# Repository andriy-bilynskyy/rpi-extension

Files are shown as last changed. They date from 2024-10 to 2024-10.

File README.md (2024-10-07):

# Raspberry Pi - Radioberry interconnection board

This project is a PCB design to create SDR transceiver using
Raspberry Pi and Radioberry boards. Simple connection of boards
seems incomplete:

- usually LCD Touch screen is used which creates EMI
- touch screen usually requires I2C bus but it's already used on a Raspberry header
- switching on/off requires USB connection - strange for complete inbox design
- no RTC
- complete design requires BMS monitoring but again I2C is already occupied

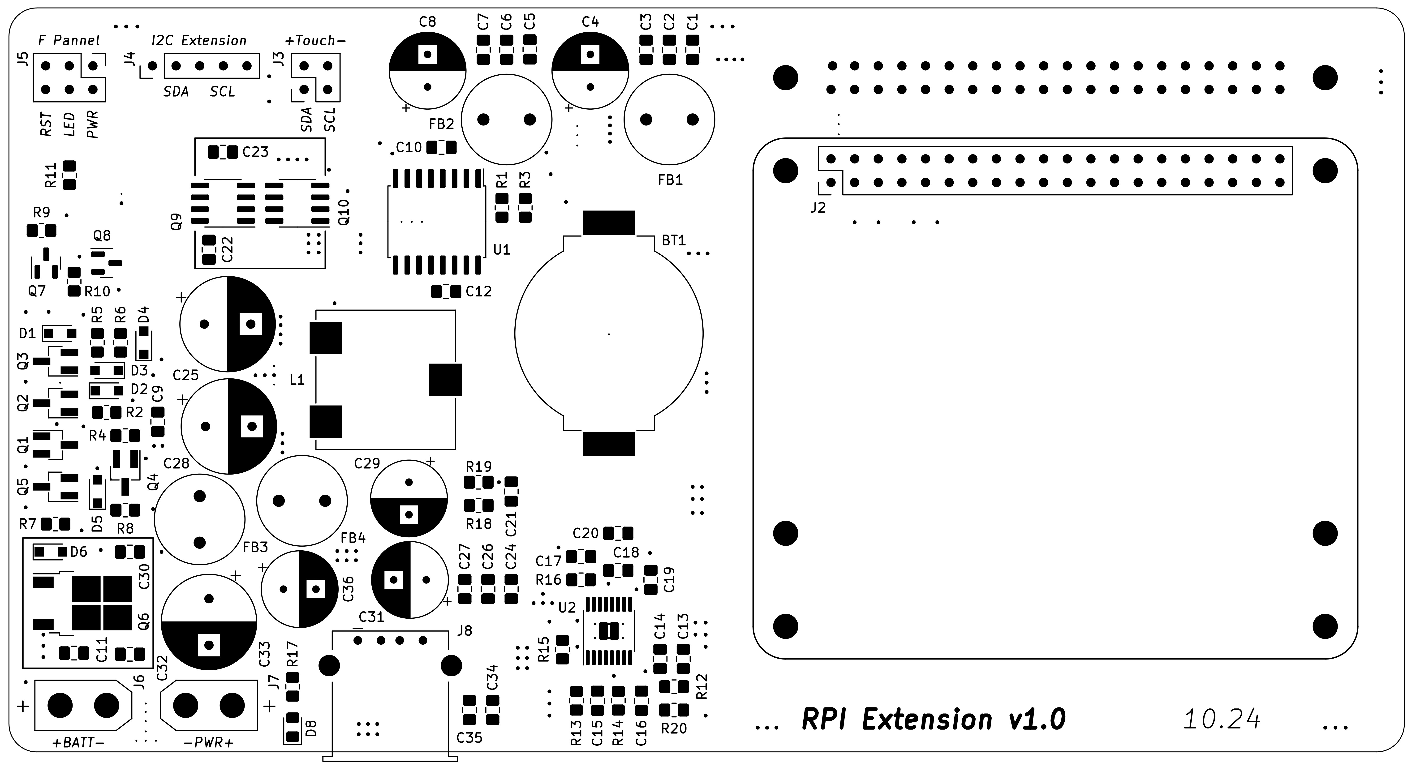
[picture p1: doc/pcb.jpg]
[](doc/pcb.jpg)

## Main Features

- Radioberry shield (mainly EMI caused by LCD touchscreen)
- 12V battery power supply (switching converter to 5V USB)
- ON/OFF circuits with indication
- RTC

For design is used KiCad Version 6.0.11

Documentation is available under **doc** folder

Prepared fabrication files under **gerber** folder

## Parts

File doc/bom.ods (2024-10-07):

Component | Footprint | Count | Designator
ICs
DS3231SN | SO-16 | 1 | U1
TPS40057PWP | HTSSOP-16 | 1 | U2
Transistors
MMBF170LT1G | SOT-23 | 4 | Q1, Q2, Q3, Q4
BC817-40 | SOT-23 | 1 | Q5
AOD403 | DPAK | 1 | Q6
BC807-40 | SOT-23 | 2 | Q7, Q8
IRF8721PBF | SO-8 | 2 | Q9, Q10
Diodes
BZX384-B12 | SOD-323 | 3 | D1, D2, D6
1N4148W | SOD-123 | 3 | D3, D4, D5
FYLS-0805BPGC | SMD 0805 | 1 | D8
Inductors
RRH-95-50-160 | D9.5x16.0 | 4 | FB1, FB2, FB3, FB4
CDEP147NP-6R1MC-125 | 14.9x14.9x8.0 | 1 | L1
Capacitors
100pF | SMD 0805 | 1 | C17
4.7nF | SMD 0805 | 1 | C16
0.1uF | SMD 0805 | 11 | C1, C2, C5, C6, C12, C15, C18, C20, C24, C30, C34
1.0uF | SMD 0805 | 6 | C9, C10, C11, C19, C22, C26
10uF | SMD 0805 | 6 | C3, C7, C23, C27, C32, C35
470uF 16V (EEUFR1C471) | D8x11.5 | 5 | C4, C8, C29, C31, C36
470uF 25V (EEUFM1E471) | D10x15 | 3 | C25, C28, C33
Resistors
51R | SMD 0805 | 1 | R10
180R | SMD 0806 | 1 | R17
220R | SMD 0807 | 2 | R6, R8
470R | SMD 0808 | 1 | R11
1.0K | SMD 0809 | 1 | R14
9.1K | SMD 0810 | 1 | R20
18K | SMD 0811 | 1 | R16
51K | SMD 0812 | 3 | R5, R7, R9
56K | SMD 0813 | 1 | R19
68K | SMD 0814 | 1 | R15
100K | SMD 0815 | 2 | R2, R4
180K | SMD 0816 | 1 | R13
Connectors
PBD-40 (ZL262-40DG) | 2x20P2.54F | 1 | J1
PLD-40 (ZL202-40G) | 2x20P2.54M | 1 | J2
PLD4 | 2x2P2.54M | 1 | J3
PLS5 | 2x5P2.54M | 1 | J4
PLD6 | 2x3P2.54M | 1 | J5
XT30 | XT30 set | 2 | J6, J7
USBA-G | USBA-1J | 1 | J8
BC-2003 | CR2032 Hold | 1 | BT1

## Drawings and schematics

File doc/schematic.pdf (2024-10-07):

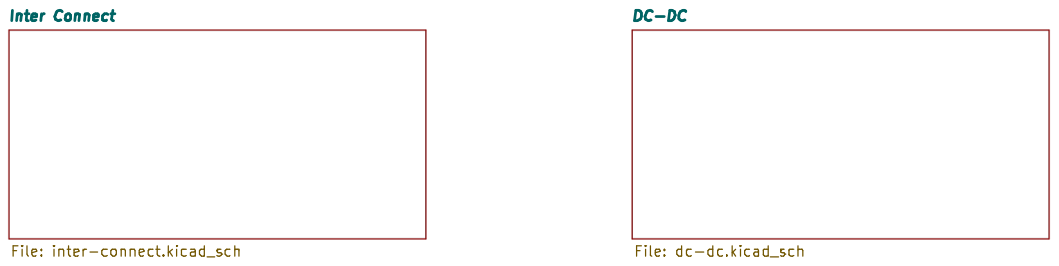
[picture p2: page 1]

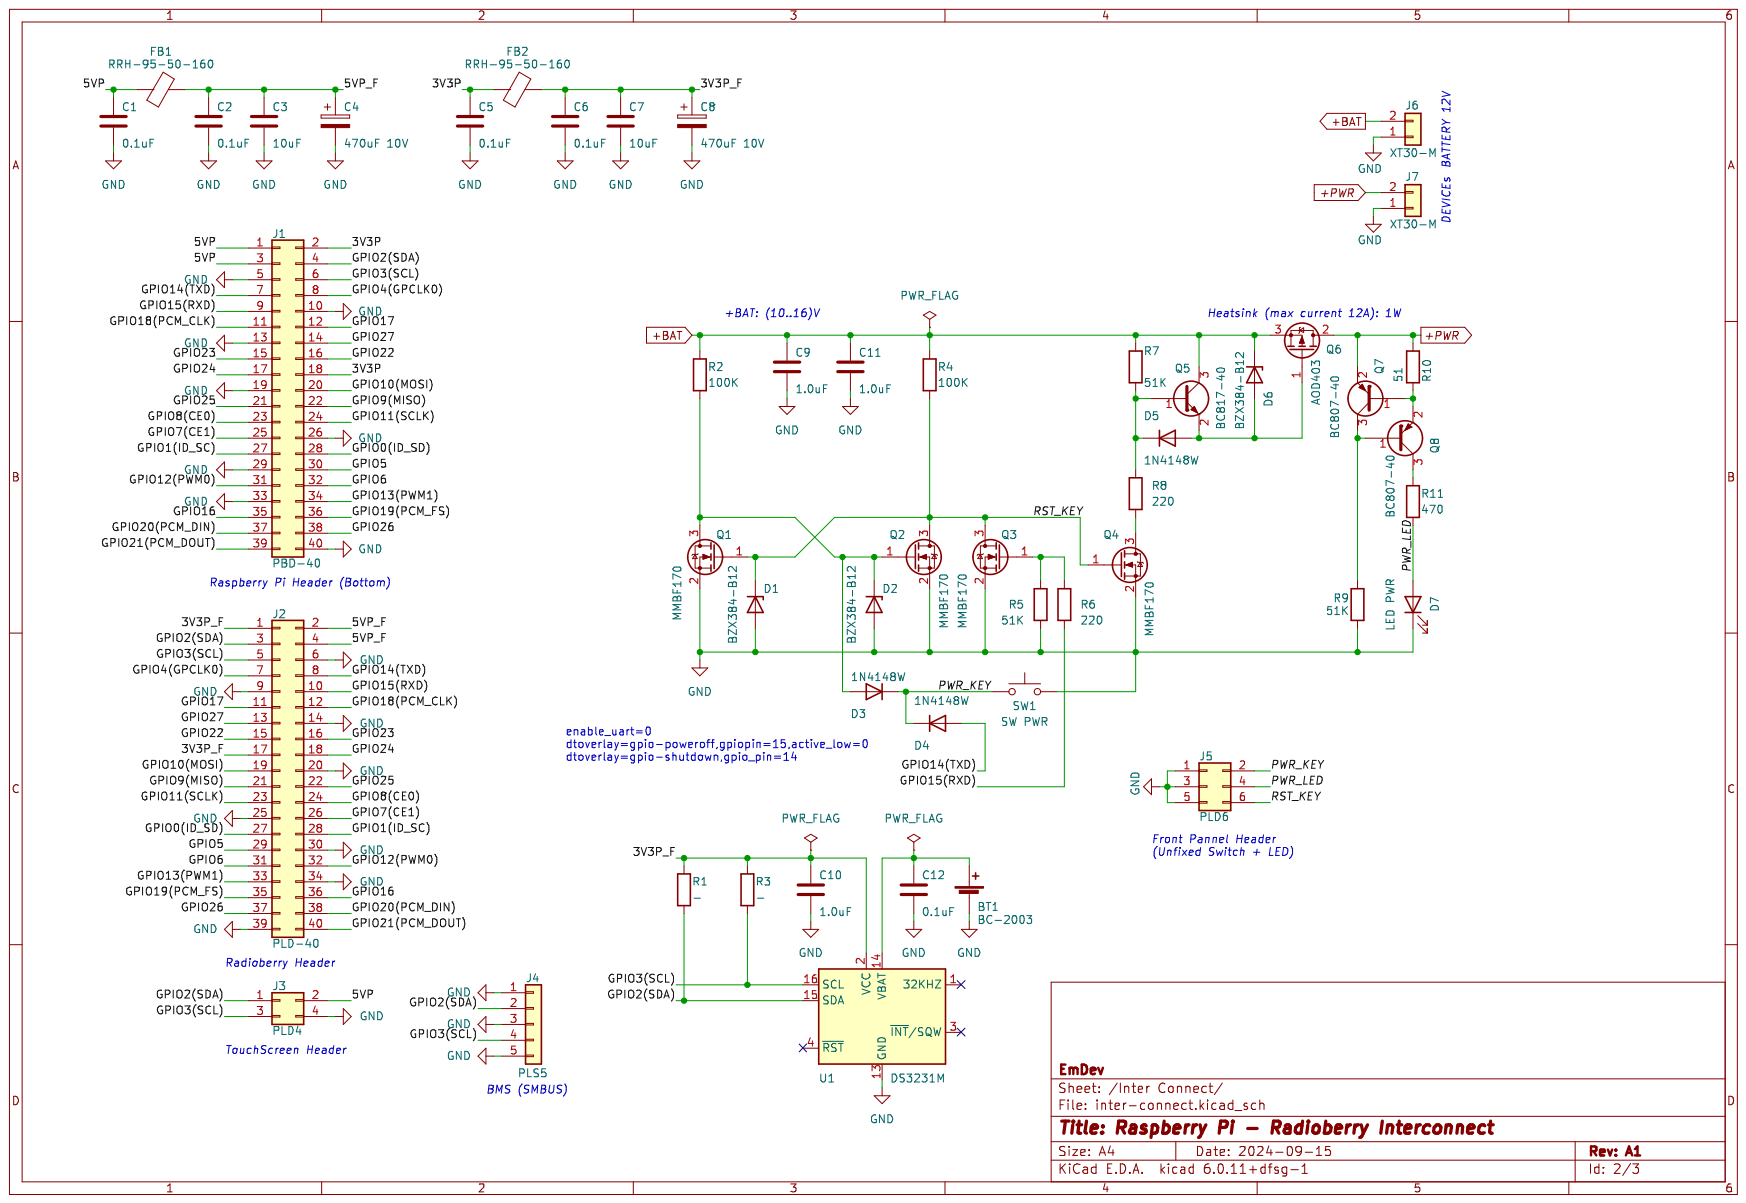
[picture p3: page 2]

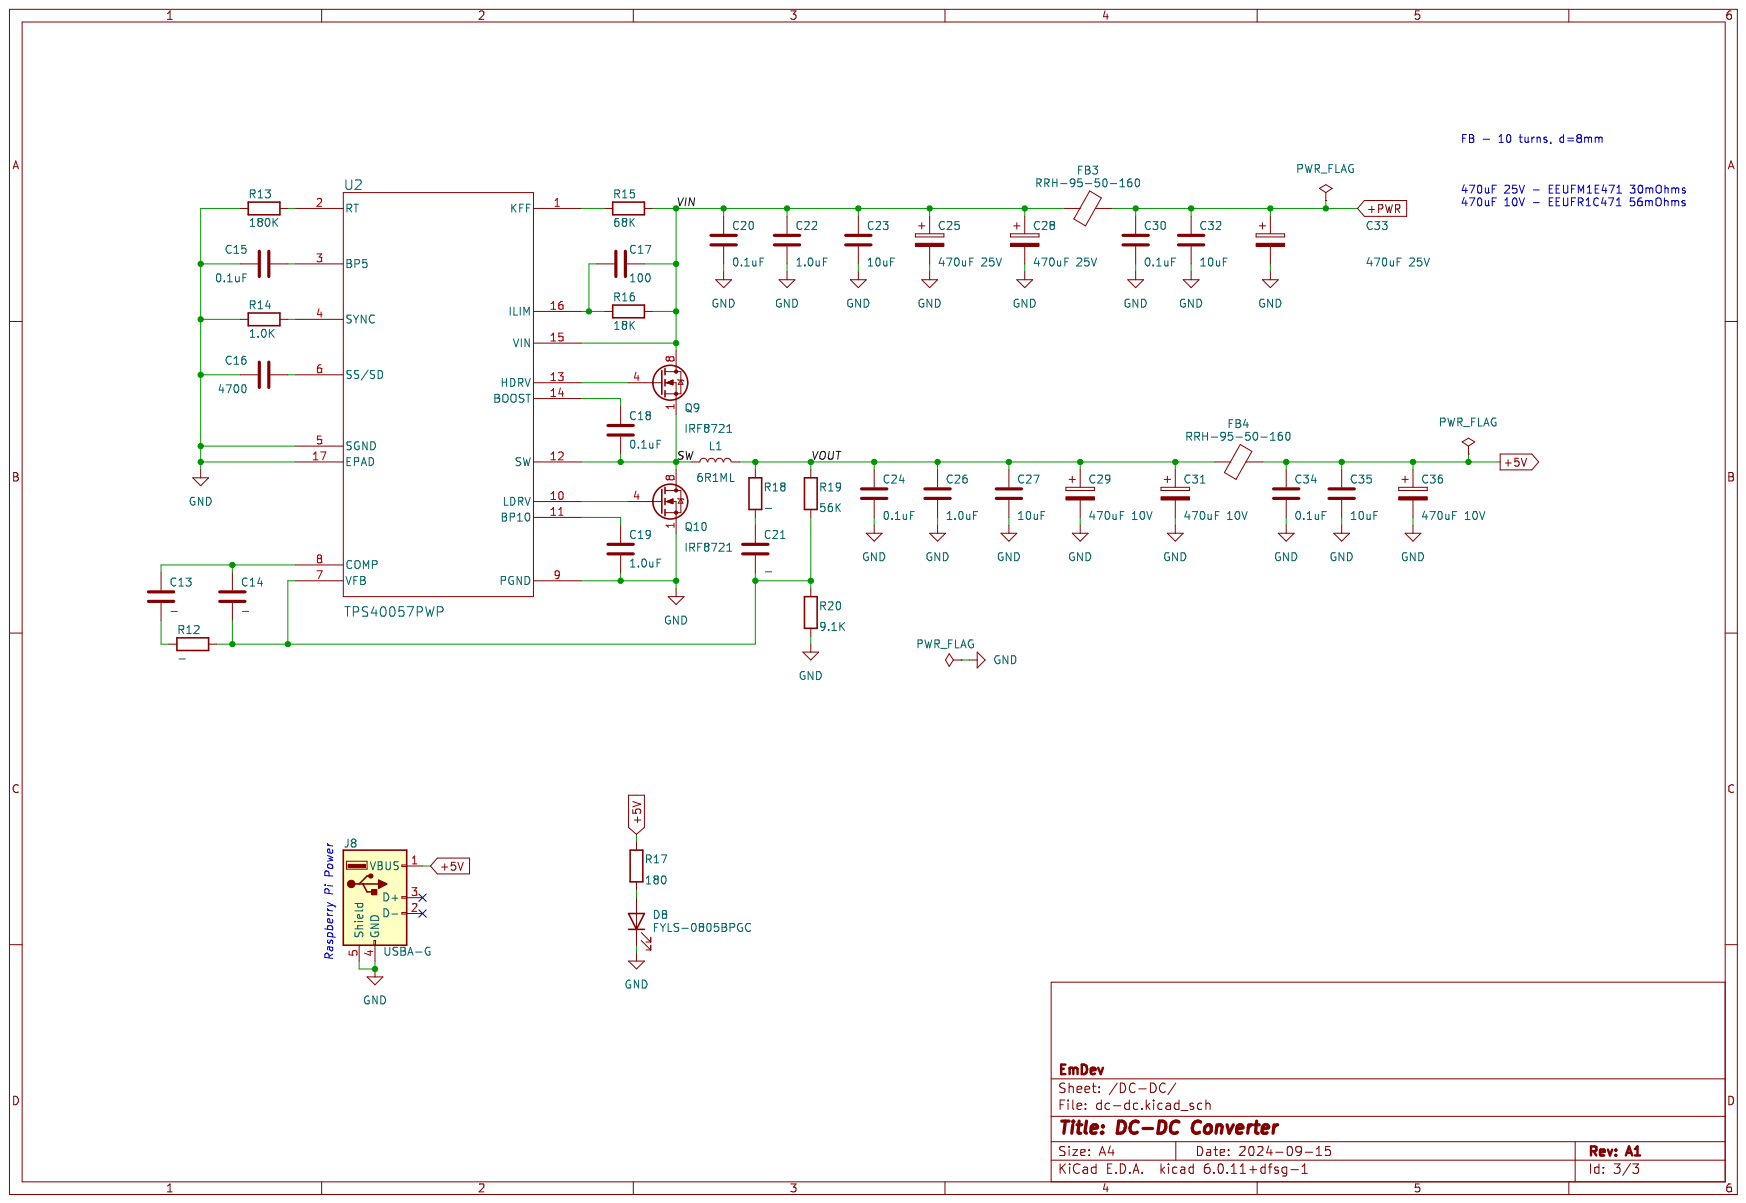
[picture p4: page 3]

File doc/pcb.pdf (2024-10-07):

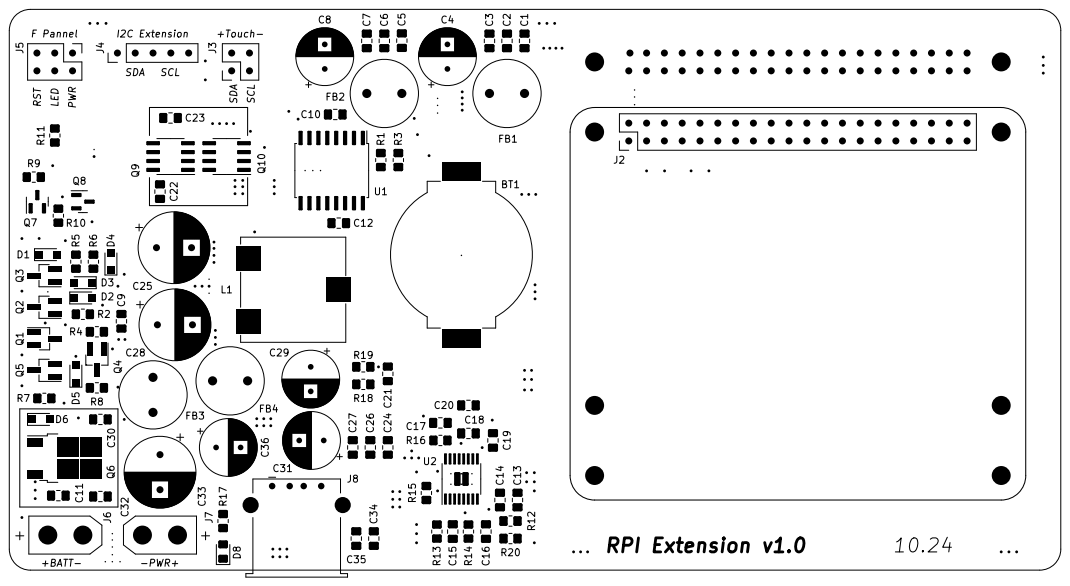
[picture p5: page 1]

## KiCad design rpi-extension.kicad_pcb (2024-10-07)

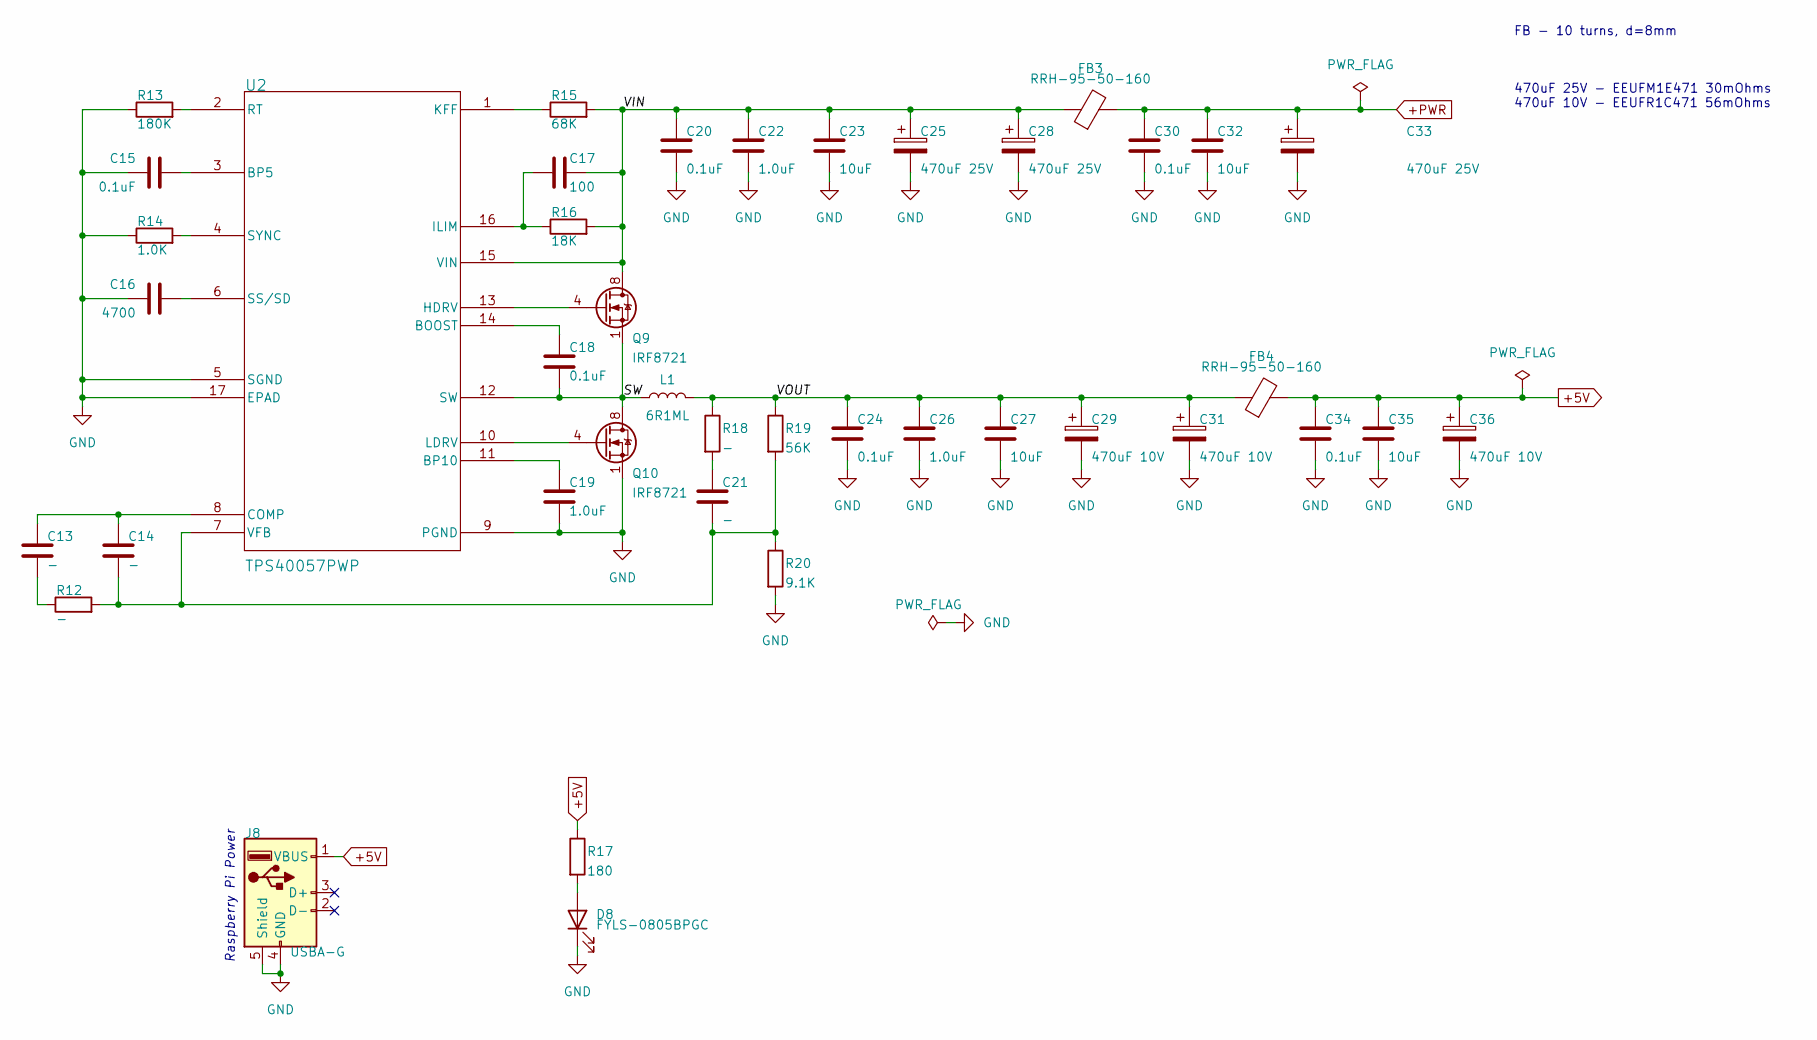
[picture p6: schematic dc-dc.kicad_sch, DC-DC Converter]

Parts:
C13, C14, C21: -; C_0805_2012Metric_Pad1.18x1.45mm_HandSolder
C15, C18, C20, C24, C30, C34: 0.1uF; C_0805_2012Metric_Pad1.18x1.45mm_HandSolder
C16: 4700; C_0805_2012Metric_Pad1.18x1.45mm_HandSolder
C17: 100; C_0805_2012Metric_Pad1.18x1.45mm_HandSolder
C19, C22, C26: 1.0uF; C_0805_2012Metric_Pad1.18x1.45mm_HandSolder
C23, C27, C32, C35: 10uF; C_0805_2012Metric_Pad1.18x1.45mm_HandSolder
C25, C28, C33: 470uF 25V; CP_Radial_D10.0mm_P5.00mm
C29, C31, C36: 470uF 10V; CP_Radial_D8.0mm_P3.50mm
D8: FYLS-0805BPGC; LED_0805_2012Metric_Pad1.15x1.40mm_HandSolder
FB3, FB4: RRH-95-50-160; L_Radial_D9.5mm_P5.00mm_Fastron_07HVP
J8: USBA-G; USB_A_Stewart_SS-52100-001_Horizontal
L1: 6R1ML; CDEP147
Q9, Q10: IRF8721; SOIC-8_3.9x4.9mm_P1.27mm
R12, R18: -; R_0805_2012Metric_Pad1.20x1.40mm_HandSolder
R13: 180K; R_0805_2012Metric_Pad1.20x1.40mm_HandSolder
R14: 1.0K; R_0805_2012Metric_Pad1.20x1.40mm_HandSolder
R15: 68K; R_0805_2012Metric_Pad1.20x1.40mm_HandSolder
R16: 18K; R_0805_2012Metric_Pad1.20x1.40mm_HandSolder
R17: 180; R_0805_2012Metric_Pad1.20x1.40mm_HandSolder
R19: 56K; R_0805_2012Metric_Pad1.20x1.40mm_HandSolder
R20: 9.1K; R_0805_2012Metric_Pad1.20x1.40mm_HandSolder
U2: TPS40057PWP; HTSSOP-16-1EP_4.4x5mm_P0.65mm_EP3.4x5mm_Mask2.46x2.31mm_The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

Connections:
+5V: C34.2, C35.2, C36.1, FB4.2, J8.1 (VBUS), R17.1
+PWR: C30.2, C32.2, C33.1, FB3.2; also elsewhere on the board
/DC-DC/SW: C18.1, L1.1, Q9.1 (S), Q9.2 (S), Q9.3 (S), Q10.5 (D), Q10.6 (D), Q10.7 (D), Q10.8 (D), U2.12 (SW)
/DC-DC/VIN: C17.1, C20.2, C22.2, C23.2, C25.1, C28.1, FB3.1, Q9.5 (D), Q9.6 (D), Q9.7 (D), Q9.8 (D), R15.2, R16.2, U2.15 (VIN)
/DC-DC/VOUT: C24.2, C26.2, C27.2, C29.1, C31.1, FB4.1, L1.2, R18.1, R19.1
GND: C15.1, C16.1, C19.1, C20.1, C22.1, C23.1, C24.1, C25.2, C26.1, C27.1, C28.2, C29.2, C30.1, C31.2, C32.1, C33.2, C34.1, C35.1, C36.2, D8.1 (K), J8.4 (GND), J8.5 (Shield), Q10.1 (S), Q10.2 (S), Q10.3 (S), R13.1, R14.1, R20.2, U2.5 (SGND), U2.9 (PGND), U2.17 (EPAD); also elsewhere on the board
unnamed: C13.1, R12.1
unnamed: C13.2, C14.2, U2.8 (COMP)
unnamed: C14.1, C21.1, R12.2, R19.2, R20.1, U2.7 (VFB)
unnamed: C15.2, U2.3 (BP5)
unnamed: C16.2, U2.6 (SS/SD)
unnamed: C17.2, R16.1, U2.16 (ILIM)
unnamed: C18.2, U2.14 (BOOST)
unnamed: C19.2, U2.11 (BP10)
unnamed: C21.2, R18.2
unnamed: D8.2 (A), R17.2
unnamed: Q9.4 (G), U2.13 (HDRV)
unnamed: Q10.4 (G), U2.10 (LDRV)
unnamed: R13.2, U2.2 (RT)
unnamed: R14.2, U2.4 (SYNC)
unnamed: R15.1, U2.1 (KFF)

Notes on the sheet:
470uF 25V - EEUFM1E471 30mOhms 470uF 10V - EEUFR1C471 56mOhms
FB - 10 turns, d=8mm
Raspberry Pi Power

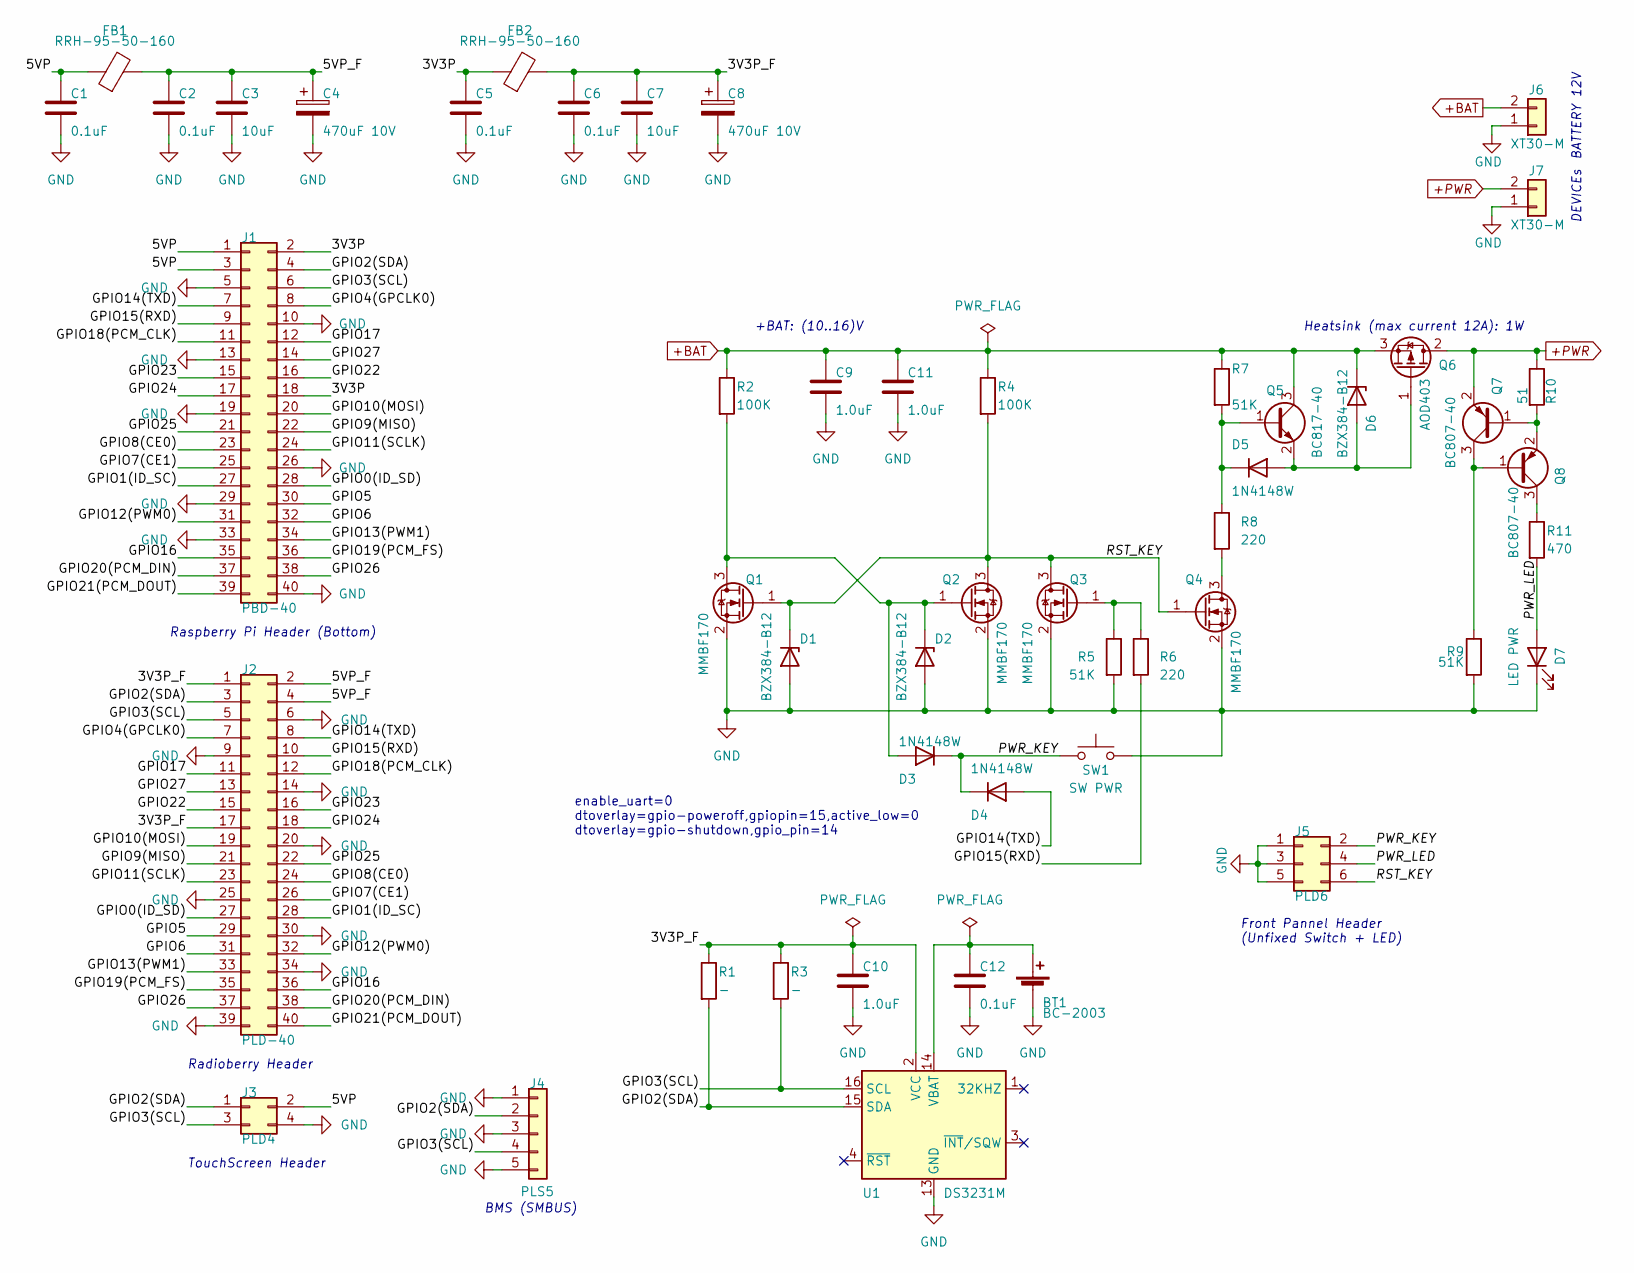
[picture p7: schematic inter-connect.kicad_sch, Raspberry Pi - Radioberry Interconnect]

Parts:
BT1: BC-2003; BatteryHolder_MPD_BC2003_1x2032
C1, C2, C5, C6, C12: 0.1uF; C_0805_2012Metric_Pad1.18x1.45mm_HandSolder
C3, C7: 10uF; C_0805_2012Metric_Pad1.18x1.45mm_HandSolder
C4, C8: 470uF 10V; CP_Radial_D8.0mm_P3.50mm
C9, C10, C11: 1.0uF; C_0805_2012Metric_Pad1.18x1.45mm_HandSolder
D1, D2, D6: BZX384-B12; D_SOD-323_HandSoldering
D3, D4, D5: 1N4148W; D_SOD-323_HandSoldering
D7: LED PWR
FB1, FB2: RRH-95-50-160; L_Radial_D9.5mm_P5.00mm_Fastron_07HVP
J1: PBD-40; PinHeader_2x20_P2.54mm_Vertical
J2: PLD-40; PinHeader_2x20_P2.54mm_Vertical
J3: PLD4; PinHeader_2x02_P2.54mm_Vertical
J4: PLS5; PinHeader_1x05_P2.54mm_Vertical
J5: PLD6; PinHeader_2x03_P2.54mm_Vertical
J6, J7: XT30-M; AMASS_XT30U-M_1x02_P5.0mm_Vertical
Q1, Q2, Q3, Q4: MMBF170; SOT-23_Handsoldering
Q5: BC817-40; SOT-23_Handsoldering
Q6: AOD403; TO-252-2
Q7, Q8: BC807-40; SOT-23
R1, R3: -; R_0805_2012Metric_Pad1.20x1.40mm_HandSolder
R2, R4: 100K; R_0805_2012Metric_Pad1.20x1.40mm_HandSolder
R5, R7, R9: 51K; R_0805_2012Metric_Pad1.20x1.40mm_HandSolder
R6, R8: 220; R_0805_2012Metric_Pad1.20x1.40mm_HandSolder
R10: 51; R_0805_2012Metric_Pad1.20x1.40mm_HandSolder
R11: 470; R_0805_2012Metric_Pad1.20x1.40mm_HandSolder
SW1: SW PWR
U1: DS3231M; SOIC-16W_7.5x10.3mm_P1.27mm

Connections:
+BAT: C9.2, C11.2, D6.1 (K), J6.2, Q5.3 (C), Q6.3 (S), R2.1, R4.1, R7.1
+PWR: J7.2, Q6.2 (D), Q7.2 (E), R10.1; also elsewhere on the board
/Inter Connect/3V3P: C5.2, FB2.1, J1.2, J1.18
/Inter Connect/3V3P_F: C6.2, C7.2, C8.1, C10.2, FB2.2, J2.1, J2.17, R1.1, R3.1, U1.2 (VCC)
/Inter Connect/5VP: C1.2, FB1.1, J1.1, J1.3, J3.2
/Inter Connect/5VP_F: C2.2, C3.2, C4.1, FB1.2, J2.2, J2.4
/Inter Connect/GPIO0(ID_SD): J1.28, J2.27
/Inter Connect/GPIO1(ID_SC): J1.27, J2.28
/Inter Connect/GPIO2(SDA): J1.4, J2.3, J3.1, J4.2, R1.2, U1.15 (SDA)
/Inter Connect/GPIO3(SCL): J1.6, J2.5, J3.3, J4.4, R3.2, U1.16 (SCL)
/Inter Connect/GPIO4(GPCLK0): J1.8, J2.7
/Inter Connect/GPIO5: J1.30, J2.29
/Inter Connect/GPIO6: J1.32, J2.31
/Inter Connect/GPIO7(CE1): J1.25, J2.26
/Inter Connect/GPIO8(CE0): J1.23, J2.24
/Inter Connect/GPIO9(MISO): J1.22, J2.21
/Inter Connect/GPIO10(MOSI): J1.20, J2.19
/Inter Connect/GPIO11(SCLK): J1.24, J2.23
/Inter Connect/GPIO12(PWM0): J1.31, J2.32
/Inter Connect/GPIO13(PWM1): J1.34, J2.33
/Inter Connect/GPIO14(TXD): D4.2 (A), J1.7, J2.8
/Inter Connect/GPIO15(RXD): J1.9, J2.10, R6.2
/Inter Connect/GPIO16: J1.35, J2.36
/Inter Connect/GPIO17: J1.12, J2.11
/Inter Connect/GPIO18(PCM_CLK): J1.11, J2.12
/Inter Connect/GPIO19(PCM_FS): J1.36, J2.35
/Inter Connect/GPIO20(PCM_DIN): J1.37, J2.38
/Inter Connect/GPIO21(PCM_DOUT): J1.39, J2.40
/Inter Connect/GPIO22: J1.16, J2.15
/Inter Connect/GPIO23: J1.15, J2.16
/Inter Connect/GPIO24: J1.17, J2.18
/Inter Connect/GPIO25: J1.21, J2.22
/Inter Connect/GPIO26: J1.38, J2.37
/Inter Connect/GPIO27: J1.14, J2.13
/Inter Connect/PWR_KEY: D3.1 (K), D4.1 (K), J5.2, SW1.1
/Inter Connect/PWR_LED: D7.2 (A), J5.4, R11.2
/Inter Connect/RST_KEY: D1.1 (K), J5.6, Q1.1 (G), Q2.3 (D), Q3.3 (D), Q4.1 (G), R4.2
GND: BT1.2 (-), C1.1, C2.1, C3.1, C4.2, C5.1, C6.1, C7.1, C8.2, C9.1, C10.1, C11.1, C12.1, D1.2 (A), D2.2 (A), D7.1 (K), J1.5, J1.10, J1.13, J1.19, J1.26, J1.29, J1.33, J1.40, J2.6, J2.9, J2.14, J2.20, J2.25, J2.30, J2.34, J2.39, J3.4, J4.1, J4.3, J4.5, J5.1, J5.3, J5.5, J6.1, J7.1, Q1.2 (S), Q2.2 (S), Q3.2 (S), Q4.2 (S), R5.2, R9.2, SW1.2, U1.5 (GND), U1.6 (GND), U1.7 (GND), U1.8 (GND), U1.9 (GND), U1.10 (GND), U1.11 (GND), U1.12 (GND), U1.13 (GND); also elsewhere on the board
unnamed: BT1.1 (+), C12.2, U1.14 (VBAT)
unnamed: D2.1 (K), D3.2 (A), Q1.3 (D), Q2.1 (G), R2.2
unnamed: D5.1 (K), Q5.1 (B), R7.2, R8.1
unnamed: D5.2 (A), D6.2 (A), Q5.2 (E), Q6.1 (G)
unnamed: Q3.1 (G), R5.1, R6.1
unnamed: Q4.3 (D), R8.2
unnamed: Q7.1 (B), Q8.2 (E), R10.2
unnamed: Q7.3 (C), Q8.1 (B), R9.1
unnamed: Q8.3 (C), R11.1

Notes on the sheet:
enable_uart=0 dtoverlay=gpio-poweroff,gpiopin=15,active_low=0 dtoverlay=gpio-shutdown,gpio_pin=14
Front Pannel Header (Unfixed Switch + LED)
BATTERY 12V
TouchScreen Header
DEVICEs
+BAT: (10..16)V
Heatsink (max current 12A): 1W
Raspberry Pi Header (Bottom)
Radioberry Header
BMS (SMBUS)

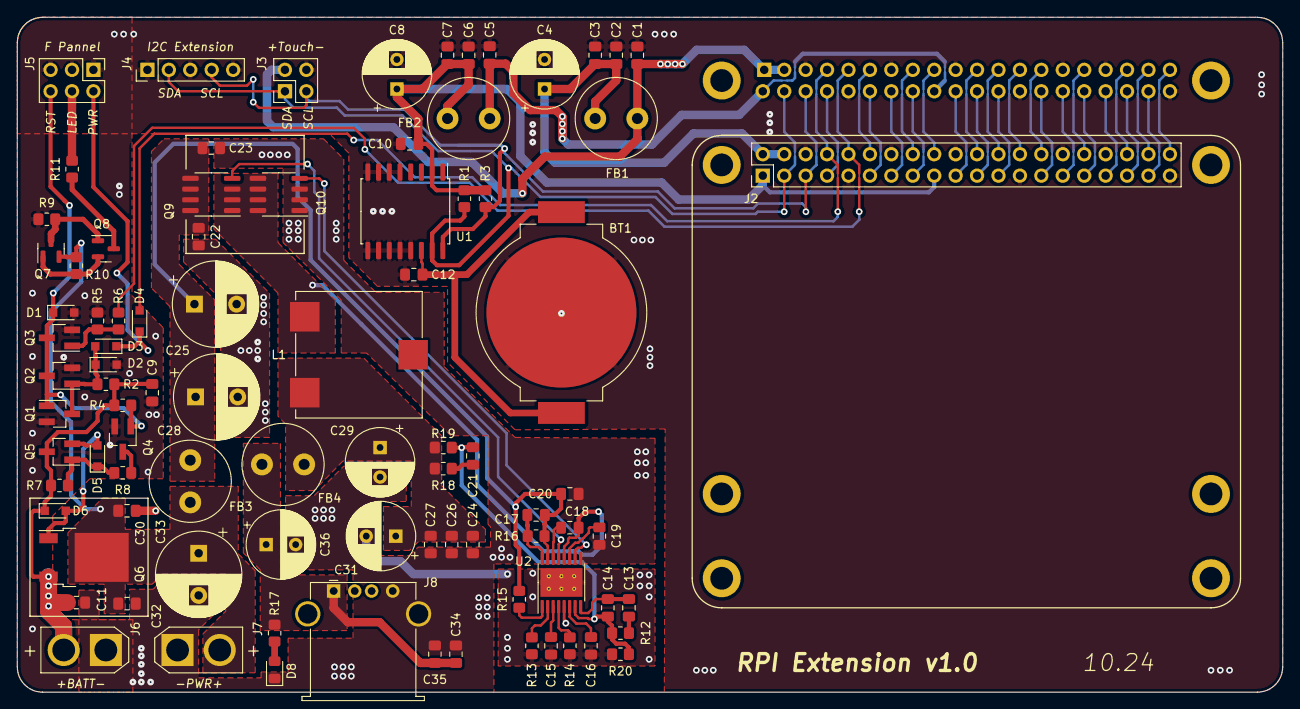
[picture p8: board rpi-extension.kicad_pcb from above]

Board: 2 copper layers, 150.0 x 80.0 mm, 89 parts (1 on the bottom side), 66 nets.

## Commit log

2024-10-07 Initial commit.
    [dc-dc.kicad_sch, inter-connect.kicad_sch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]
2024-10-07 Add build of materials.
    [bom.ods]
